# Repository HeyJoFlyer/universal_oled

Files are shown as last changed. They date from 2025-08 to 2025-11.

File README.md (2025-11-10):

# Open ESP32 Smart OLED Display Hardware

### Free as in Freedom

This repository provides the complete open-source hardware design for a compact, Wi-Fi-capable smart display using an ESP32 and a 128x64 I2C OLED module. The project includes a manufacturable PCB and a 3D-printable case. An optional capacitive touch sensor can be added to the case.

This project is ideal for developers who want to integrate a small display into smart home interfaces, information kiosks, sensor dashboards, or other embedded projects. Examples include uses with ESPHome for HomeAssistant or weather display.

## Hardware Overview

- ESP32-based design (supports Wi-Fi and Bluetooth)
- 128x64 I2C OLED (SSD1306 or similar)
- Optional touch sensor header (TTP223)
- Compact 3D-printable enclosure
- USB C power
- Designed for easy customization and integration
- Parts sourced from Digikey find list [here](./hardware/components.md)
- Display, touch sensor and USB C port sourced from aliexpress
- PCB ordered from [PCBWay](https://www.pcbway.com)

### PCB Highlights

- Minimal footprint
- Breakout headers for touch input
- Unused GPIO exposed for easy expansion
- Designed using only free software (KiCad and FreeCAD)
- High quality PCB ordered from [PCBWay](https://www.pcbway.com)

## Requirements

- ESP32-WROOM Module (ESP-WROOM-C2)
- 128x64 OLED display with I2C interface
- TTP223 Capacitive Touch sensor module (optional)
- USB C Connector (with 5.1k resistor) for programming and powering the display
- Soldering equipment
- 3D printer for case (optional but recommended)
- PCB

## Usage

This repository provides the physical design only. You are free to write or upload your own firmware using Arduino, PlatformIO, or ESP-IDF. I2C display and touch sensor libraries are widely supported.

For a full list of pin connections and assembly steps, see [hardware/assembly.md](./hardware/assembly.md).

## License

This project is licensed under the MIT License. You are free to use, modify, and distribute it as needed.

## Contributing

Issues and pull requests for improvements to the hardware design or enclosure are welcome.

### Notes
- I have used a cheap USB C breakout to which I added only a single 5.1 k resistor (which is technically is not within USB spec, but it works)
- The antenna of the WROOM module is not blocked by any traces on thee main pcb, however it could possibly interfere with the display. In practice the module works fine and no interference is noticed.
- In the future I will design another open smart display again using an ESP WROOM boards and an SPI LCD Screen.

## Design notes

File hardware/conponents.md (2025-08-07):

## Components required (sourced from digikey)

[ESP32-C3-WROOM-02-N4](https://www.digikey.com/en/products/detail/espressif-systems/ESP32-C3-WROOM-02-N4/14553031) main ESP module, this included Wifi and Bluetooth

[TLV74033PDBVR](https://www.digikey.com/en/products/detail/texas-instruments/TLV74033PDBVR/12642183) cheap 3.3V regulator (max 5V in, which is fine for USB and max 300mA)

[0603 4.7 µF ceramic capacitor](https://www.digikey.com/en/products/detail/samsung-electro-mechanics/CL10A475KQ8NNNC/3886703) required

[0402 5.1kΩ resistor](https://www.digikey.com/en/products/detail/yageo/AC0402FR-075K1L/5895438) required, if your USB C breakout board needs it (most absolutely do)

## Components (sourced from Aliexpress)

USB C Breakout board

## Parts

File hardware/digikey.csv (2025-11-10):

Index | Quantity | Part Number | Manufacturer Part Number | Description | Customer Reference | Available | Backorder | Unit Price | Extended Price USD
1 | 1 | 1965-ESP32-C3-WROOM-02-N4CT-ND | ESP32-C3-WROOM-02-N4 | RF TXRX MODULE BT PCB TRACE SMD |  | 1 | 0 | 3.28000 | 3.28
2 | 1 | 296-TLV74033PDBVRCT-ND | TLV74033PDBVR | IC REG LINEAR 3.3V 300MA SOT23-5 |  | 1 | 0 | 0.10000 | 0.10
3 | 1 | 1276-1045-1-ND | CL10A475KQ8NNNC | CAP CER 4.7UF 6.3V X5R 0603 |  | 1 | 0 | 0.08000 | 0.08
4 | 1 | 1276-CL10B104KB8NNNLCT-ND | CL10B104KB8NNNL | CAP CER 0.1UF 50V X7R 0603 |  | 1 | 0 | 0.08000 | 0.08

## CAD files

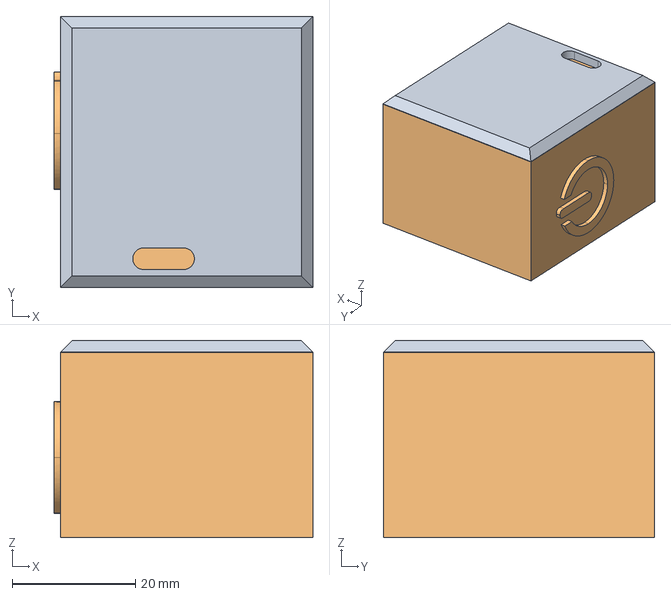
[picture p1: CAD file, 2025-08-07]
hardware/case_source/Enclosure.FCStd
42.0 x 44.0 x 32.0 mm
Cover
Enclosure

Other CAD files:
hardware/Enclosure.3mf

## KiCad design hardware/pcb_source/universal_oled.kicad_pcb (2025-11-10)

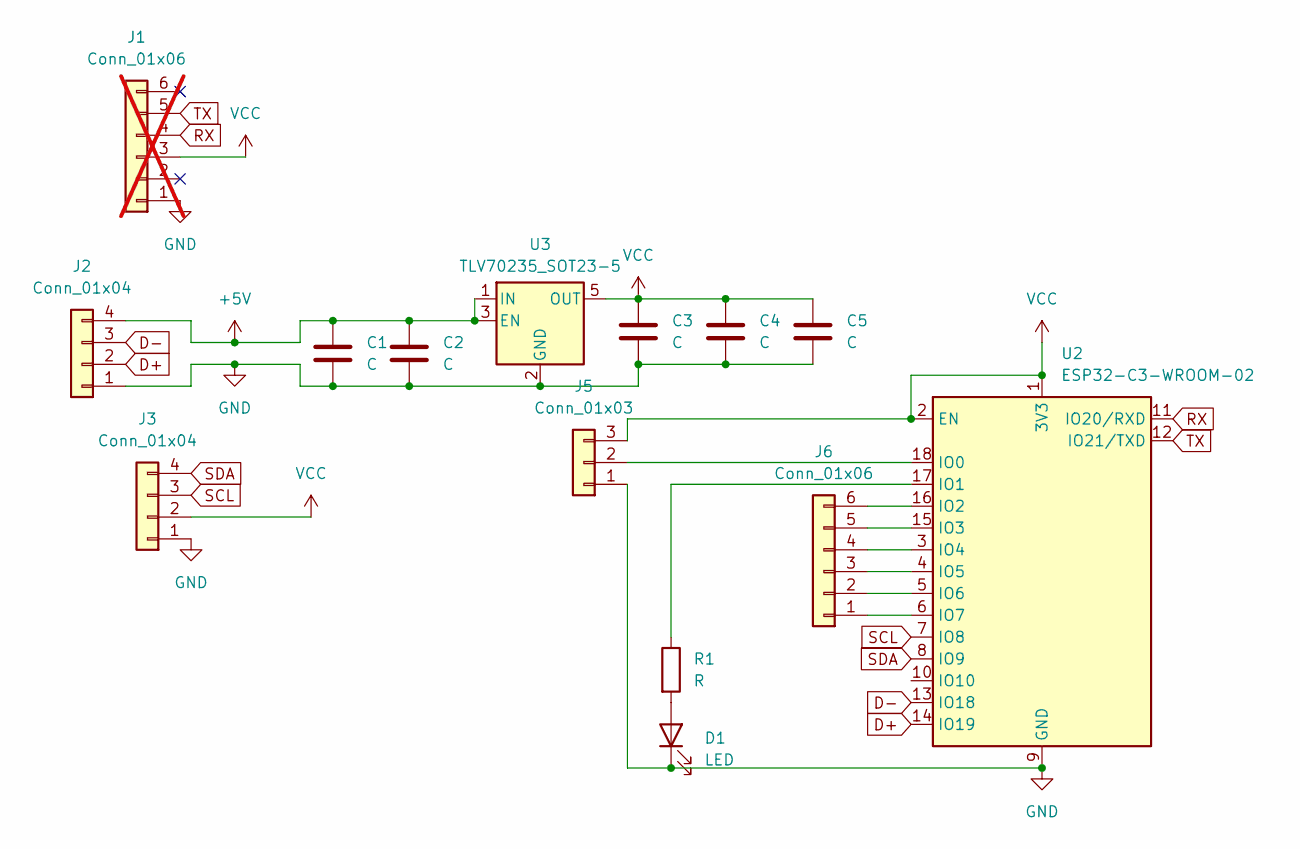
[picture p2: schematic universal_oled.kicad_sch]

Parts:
C1, C2, C3, C4: C; C_0603_1608Metric_Pad1.08x0.95mm_HandSolder
C5: C; C_0805_2012Metric_Pad1.18x1.45mm_HandSolder
D1: LED; LED_0805_2012Metric_Pad1.15x1.40mm_HandSolder
J1: Conn_01x06; PinHeader_1x06_P2.54mm_Vertical; not fitted
J2: Conn_01x04; JST_XH_B4B-XH-A_1x04_P2.50mm_Vertical
J3: Conn_01x04; PinHeader_1x04_P2.54mm_Vertical
J5: Conn_01x03; PinHeader_1x03_P2.54mm_Vertical
J6: Conn_01x06; PinHeader_1x06_P2.54mm_Vertical_SMD_Pin1Left
R1: R; R_0603_1608Metric_Pad0.98x0.95mm_HandSolder
U2: ESP32-C3-WROOM-02; ESP-WROOM-02
U3: TLV70235_SOT23-5; SOT-23-5

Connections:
+5V: C1.1, C2.1, J2.4, U3.1 (IN), U3.3 (EN)
D+: J2.2, U2.14 (IO19)
D-: J2.3, U2.13 (IO18)
GND: C1.2, C2.2, C3.2, C4.2, C5.2, D1.1 (K), J1.1, J2.1, J3.1, J5.1, U2.9 (GND), U2.19 (GND), U3.2 (GND)
unnamed: D1.2 (A), R1.2
unnamed: J5.2, U2.18 (IO0)
unnamed: J6.1, U2.6 (IO7)
unnamed: J6.2, U2.5 (IO6)
unnamed: J6.3, U2.4 (IO5)
unnamed: J6.4, U2.3 (IO4)
unnamed: J6.5, U2.15 (IO3)
unnamed: J6.6, U2.16 (IO2)
unnamed: R1.1, U2.17 (IO1)
RX: J1.4, U2.11 (IO20/RXD)
SCL: J3.3, U2.7 (IO8)
SDA: J3.4, U2.8 (IO9)
TX: J1.5, U2.12 (IO21/TXD)
VCC: C3.1, C4.1, C5.1, J1.3, J3.2, J5.3, U2.1 (3V3), U2.2 (EN), U3.5 (OUT)

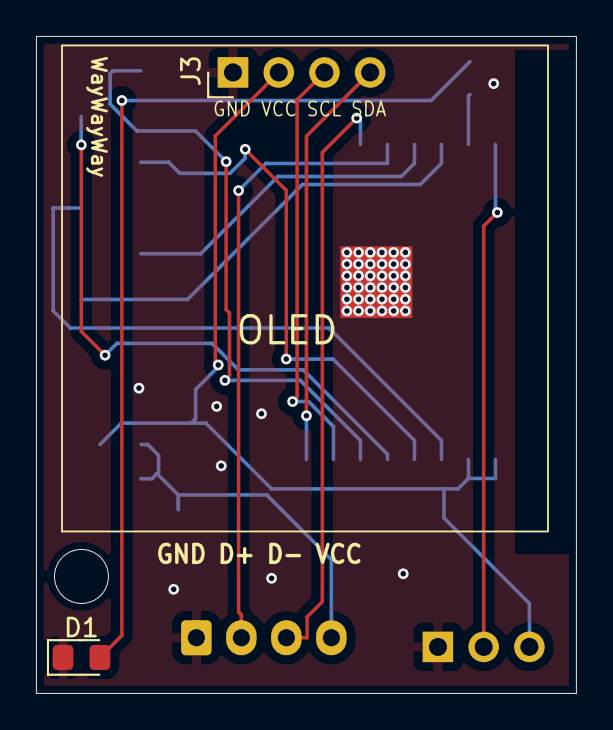
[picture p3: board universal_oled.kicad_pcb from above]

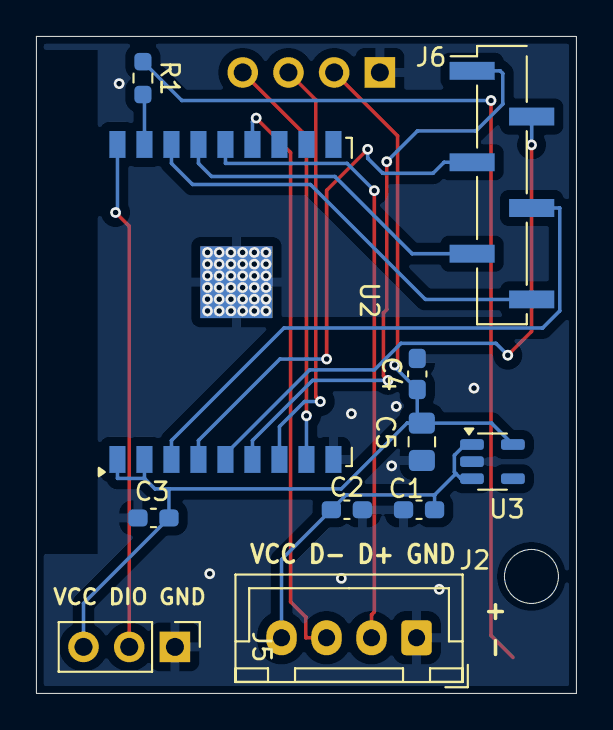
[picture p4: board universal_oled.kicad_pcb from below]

Board: 2 copper layers, 30.0 x 36.5 mm, 13 parts (11 on the bottom side), 16 nets.

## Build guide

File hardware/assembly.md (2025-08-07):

# ESP32 Smart OLED Display – Assembly Instructions

These instructions cover the mechanical and electrical assembly of the ESP32 Smart OLED Display hardware. This project does not include firmware. You are expected to upload or develop your own software using the ESP32 platform of your choice.

## WIP

## Components Required

Components required can be found [here](./components.md) (list for digikey components.)

### Required
- 1 × ESP32 Dev Module (WROOM-32 recommended)
- 1 × 0.96" 128x64 OLED Display (I2C, SSD1306)
- 1 × Custom PCB (Gerbers provided)
- 1 × 3D Printed Case
- Wires, solder
- Any type of glue

### Optional
- 1 × Capacitive Touch Sensor Module (TTP223)
- JST XTH connector for better modularity

## Tools Required

- Soldering iron and solder
- Flush cutters
- 3D printer (or access to one)
- Multimeter (optional for verification)

---

## Step-by-Step Assembly

### 1. PCB Fabrication

- Send the gerber `hardware/gerber.zip` to a PCB manufacturer (i used [PCBWay](https://www.pcbway.com)).
- Choose 1mm or 1.2mm thickness
- For sustainability choose HASL Lead free or ENIG (ENIG is absolutely not needed)

### 2. Soldering Components

- Solder the ESP32 module to the PCB.
- Solder the OLED module headers.
- Solder optional headers for the touch sensor if you plan to use one.

### 3. Touch Sensor (Optional)

- If using a touch sensor (TTP223 or similar), mount it on cutout spot and wire it to the dedicated header or directly to the PCB.
- It connects to a single GPIO pin. Ensure your firmware reads this pin with pullup enabled.

### 4. 3D Printed Case

- Print the case file `case/Enclosure.3mf`. (Print both the back cover and the main case)
- Use PLA or ABS with standard print settings.
- Insert the assembled PCB into the case and glue it in place.
- Glue the touch sensor (optional) and USB-C connector.
- Close the housing with glue after you have confirmed that your board works and you have flashed the correct firmware.

---

## Custom Firmware

This hardware supports any firmware platform compatible with ESP32 and SSD1306 OLEDs:

Example features you could add:
- Display time, temperature, humidity
- Wi-Fi signal or IP address
- API-based data (weather, calendars)
- Touch-based toggle display modes

---

## Notes

- OLED default I2C address is usually `0x3C`.
- I2C pins are typically GPIO 21 (SDA) and GPIO 22 (SCL) on ESP32.
- If the touch sensor is not responsive, verify GPIO configuration in your firmware.
- If you use the ESP32-C3-WROOM-02 module or similar you can connect GPIO 18 and GPIO 19 to the data lines of the Usb C connector for easy reflashing according to the [datasheet](https://www.espressif.com/sites/default/files/documentation/esp32-c3-wroom-02_datasheet_en.pdf).

---

## Contact

For questions or contributions, open an issue on the GitHub repository.

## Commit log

2025-08-07 Added production files
    [Enclosure.3mf, Enclosure.FCStd, universal_oled.kicad_pcb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]
2025-11-10 New PCB version
    [digikey.csv, universal_oled.kicad_pcb, universal_oled.kicad_sch]
